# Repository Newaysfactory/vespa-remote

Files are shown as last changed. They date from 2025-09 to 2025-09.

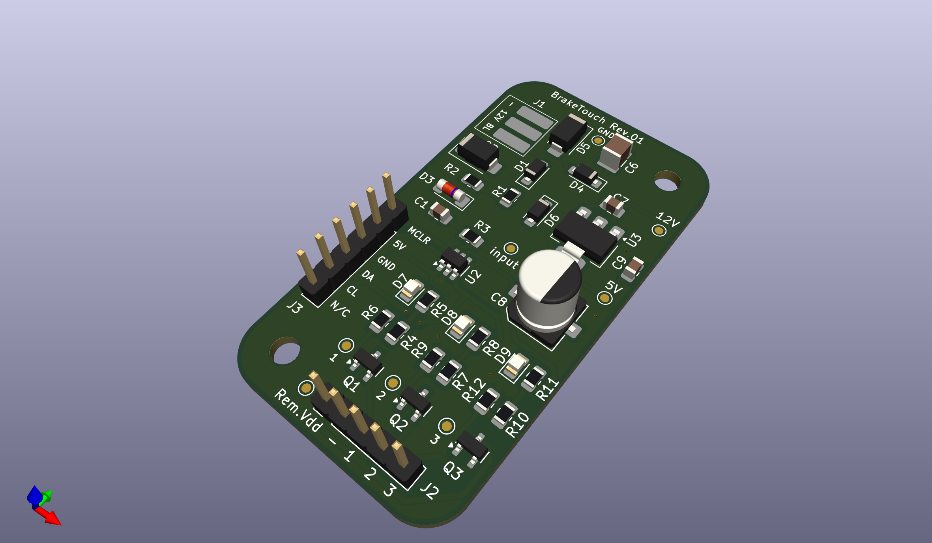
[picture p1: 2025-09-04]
electronics/KiCAD/Drawings/rev1/3DVespaRemoteControl-Front30deg.png

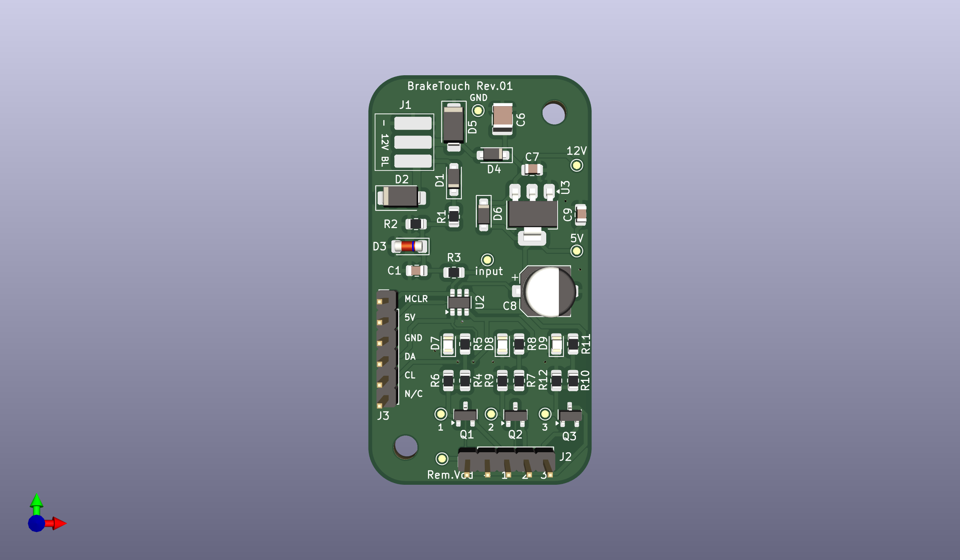
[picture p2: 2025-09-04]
electronics/KiCAD/Drawings/rev1/3DVespaRemoteControl-FrontSmall.png

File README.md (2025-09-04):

# vespa-remote
Vespa remote project - a microcontroller based circuit to trigger a gate remote using brake light signal on my Piaggio Vespa
See related youtube video https://youtu.be/zYhpTBYlj2o

## Repo content
 - Electronics - Contains the electronic hardware design (schematics and PCB) created with the free software KiCAD 8.0. Components part numbers are in the spreadsheet BOM_VespaRemoteControl.kicad_pcb.xls 
 - sw - Contains the sw project in MPLAB X IDE v6.25
 - mechanical - Contains the enclosure design in Rhinoceros 8 format. Standard STEP files are available under mechanical\fabrication\

Enjoy

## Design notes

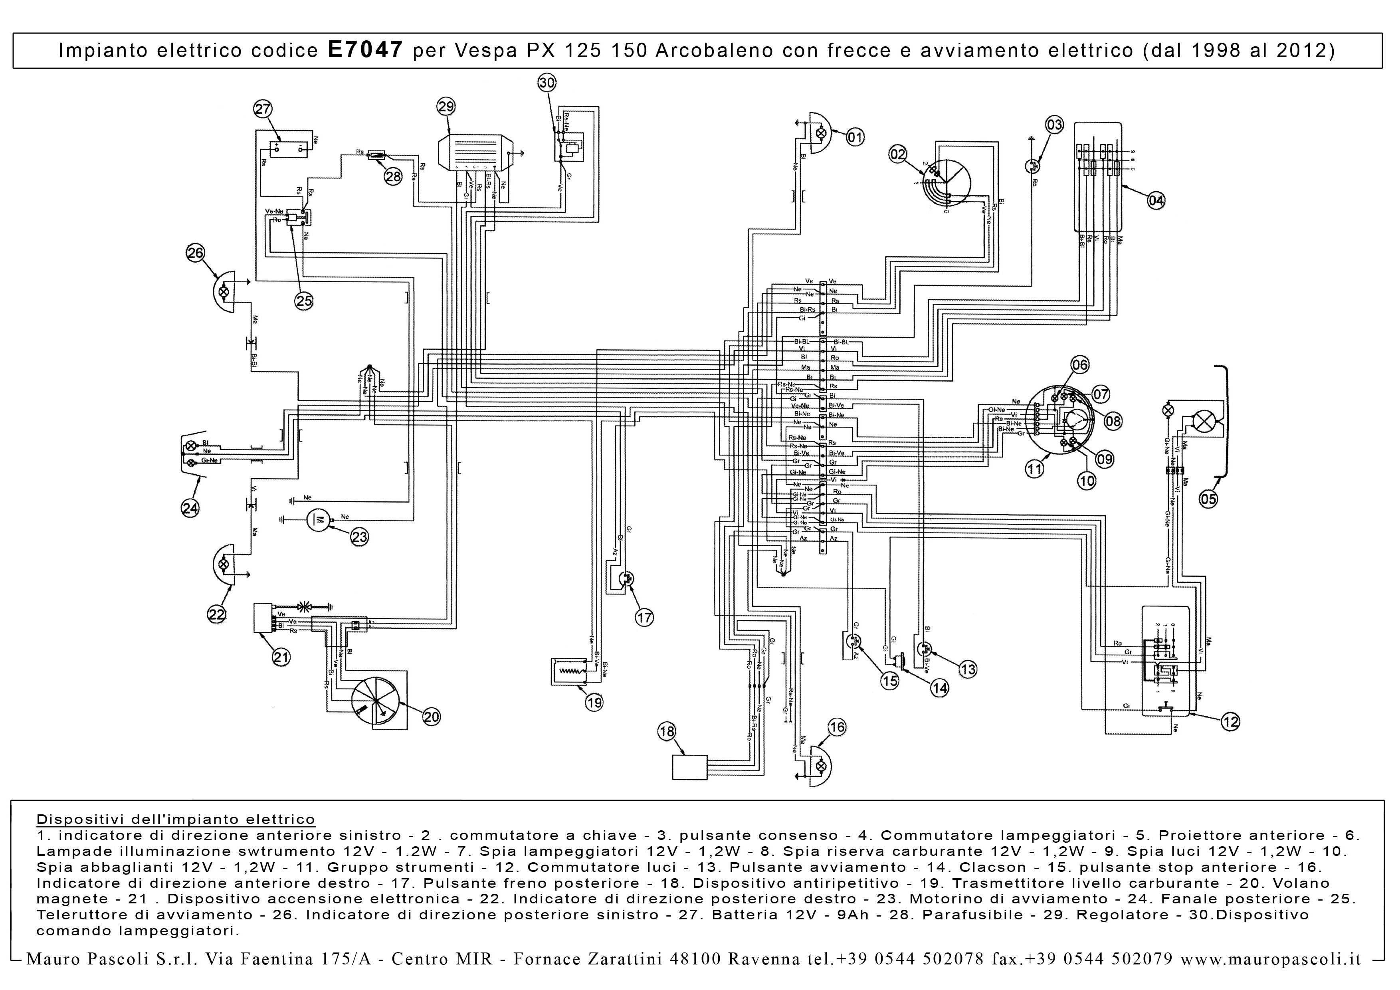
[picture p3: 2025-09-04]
VespaSchematicE7047.jpg

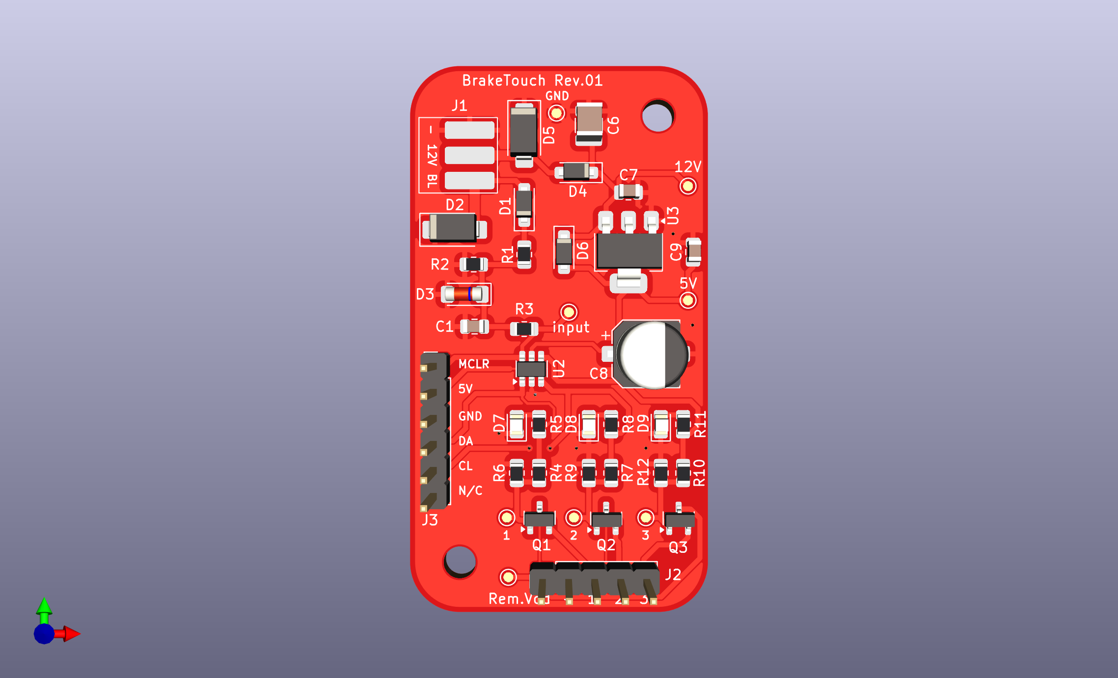
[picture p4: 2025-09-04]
electronics/KiCAD/Drawings/rev1/3DVespaRemoteControl-RedFrontSmall.png

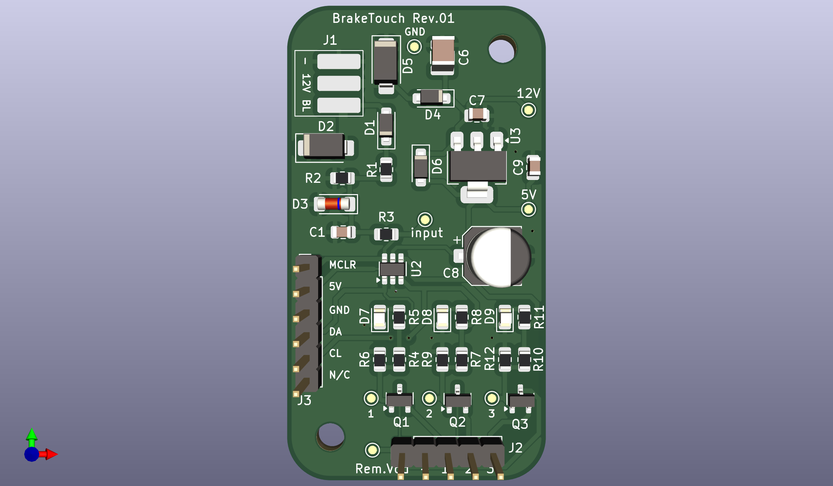
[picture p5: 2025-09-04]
electronics/KiCAD/Drawings/rev1/3DVespaRemoteControl-Front.png

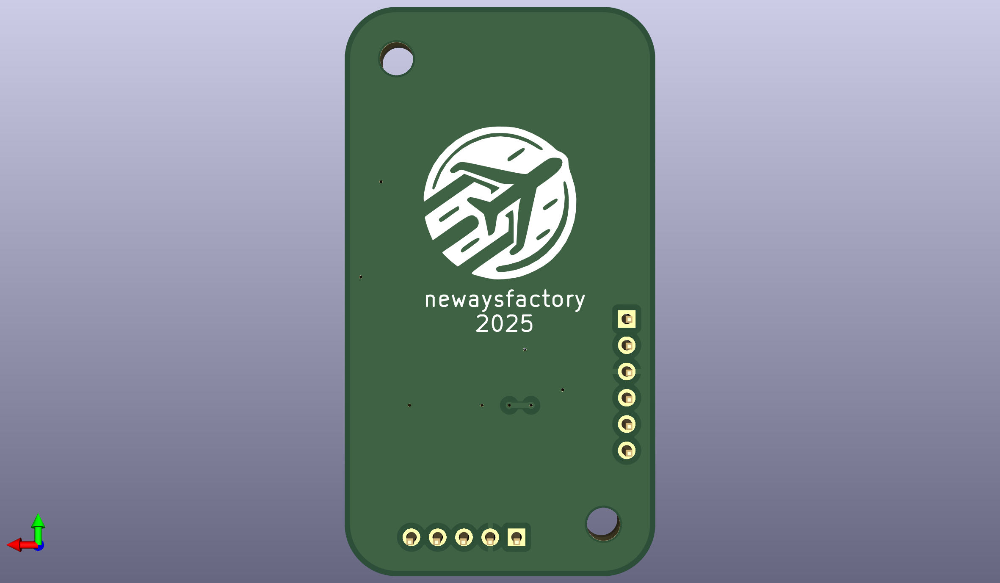
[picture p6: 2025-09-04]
electronics/KiCAD/Drawings/rev1/3DVespaRemoteControl-Back.png

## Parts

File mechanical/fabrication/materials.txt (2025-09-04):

Top cover:
Milled: Polycarbonate (PC) (transparent) Maximum service temperature	144 °C

Bottom:
3D printed: ABS

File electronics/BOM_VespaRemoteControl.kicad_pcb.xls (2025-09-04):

Designator | Quantity | Value | Footprint | Package | MPN | DNP | Mount_Type | Description | P/N
C1 | 1 | 330nF | C_0805_2012Metric |  |  |  | smt | Unpolarized capacitor, small symbol | CL21B334KBFNNNE
C6 | 1 | 10uF 100V | C_1210_3225Metric |  |  |  | smt | Unpolarized capacitor, small symbol | GRM32EC72A106KE05L
C7, C9 | 2 | 100nF100V | C_0805_2012Metric |  |  |  | smt | Unpolarized capacitor, small symbol | CL21B104KCFNNNE
C8 | 1 | 100uF | CP_Elec_6.3x7.7 |  |  |  | smt | Polarized capacitor, small symbol | EMZA350ARA101MF80G
D1, D4, D6 | 3 | 1n4007 | D_SOD-123FL |  |  |  | smt | Diode | 1N4007
D2, D5 | 2 | SMAJ30CA | D_SMA |  |  |  | smt | 400W bidirectional Transient Voltage Suppressor, 30.0Vr, SMA(DO-214AC) | SMAJ30CA
D3 | 1 | 4.7V | D_MiniMELF |  |  |  | smt | 4.7V, 500mW, 5%, Zener diode, MiniMELF | BZV55C4V7
D7, D8, D9 | 3 | LED red | LED_0805_2012Metric |  |  |  | smt | Light emitting diode | NCD0805R1
J2 | 1 | Conn_01x05 | PinHeader_1x05_P2.54mm_Vertical |  |  |  | tht | Generic connector, single row, 01x05, script generated (kicad-library-utils/schlib/autogen/connector/) | PinHeader_1x05_P2.54mm_Vertical
J3 | 1 | Conn_PIC_ICSP_ICD | PinHeader_1x06_P2.54mm_Vertical |  |  |  | tht | Microchip PIC In-Circuit Serial Programming/Debugging (ICSP/ICD) connector | PinHeader_1x06_P2.54mm_Vertical
Q1, Q2, Q3 | 3 | BC817 | SOT-23 |  |  |  | smt | 0.8A Ic, 45V Vce, NPN Transistor, SOT-23 | BC817
R1, R11, R5, R8 | 4 | 1,5k | R_0805_2012Metric |  |  |  | smt | Resistor | 0805W8F1501T5E
R10, R3, R4, R7 | 4 | 10k | R_0805_2012Metric |  |  |  | smt | Resistor | 0805W8F1002T5E
R12, R6, R9 | 3 | 100k | R_0805_2012Metric |  |  |  | smt | Resistor | 0805W8F1003T5E
R2 | 1 | 47k | R_0805_2012Metric |  |  |  | smt | Resistor | 0805W8F4702T5E
TP1, TP3, TP4, TP5, TP6, TP7, TP8, TP9 | 8 | TestPoint | My-TestPoint_Pad_D1.0mm |  |  |  | tht | test point
U2 | 1 | PIC10F222 | SOT-23-6 |  |  |  | smt | 512W Flash, 24B SRAM, SOT-23-6 | PIC10F222T-E/OT
U3 | 1 | TLV1117-50 | SOT-223-3_TabPin2 |  |  |  | smt | 800mA Low-Dropout Linear Regulator, 5.0V fixed output, TO-220/TO-252/TO-263/SOT-223 | TLV1117-50IDCY

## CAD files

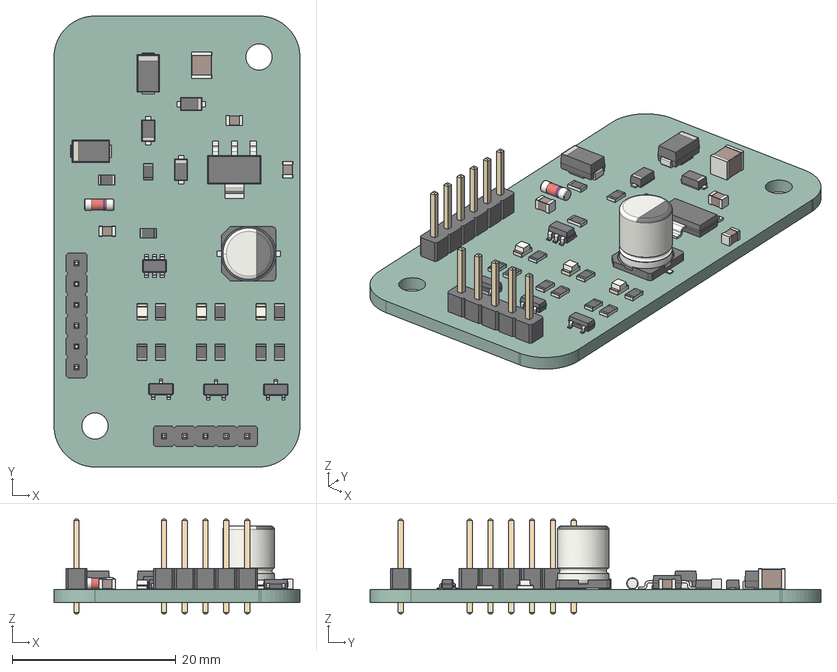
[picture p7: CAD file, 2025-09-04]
electronics/KiCAD/Drawings/rev1/VespaRemoteControl.step
30.0 x 55.0 x 11.5 mm
R_0805_2012Metric x 12
PinHeader_1x05_P254mm_Vertical
C_0805_2012Metric x 3
SOT_223
C_1210_3225Metric
CP_Elec_63x77
SOT_23 x 3
LED_0805_2012Metric x 3
D_SMA x 2
D_SOD_123F x 3
PinHeader_1x06_P254mm_Vertical
D_MiniMELF_Standard
SOT_23_6
_autosave-VespaRemoteControl_PCB

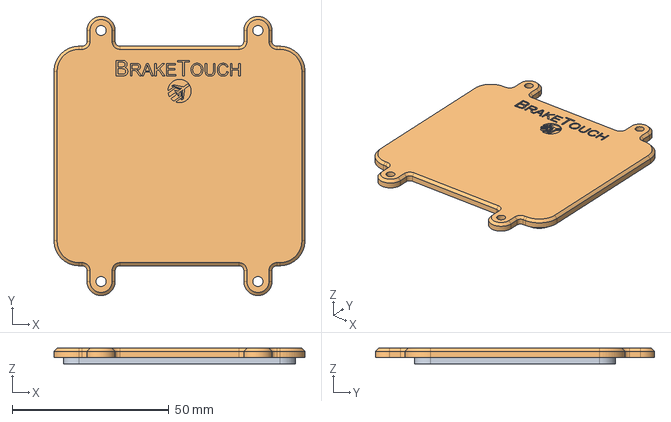
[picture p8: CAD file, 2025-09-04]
mechanical/fabrication/EnclosureTop_v2.stp
80.0 x 89.0 x 5.00 mm

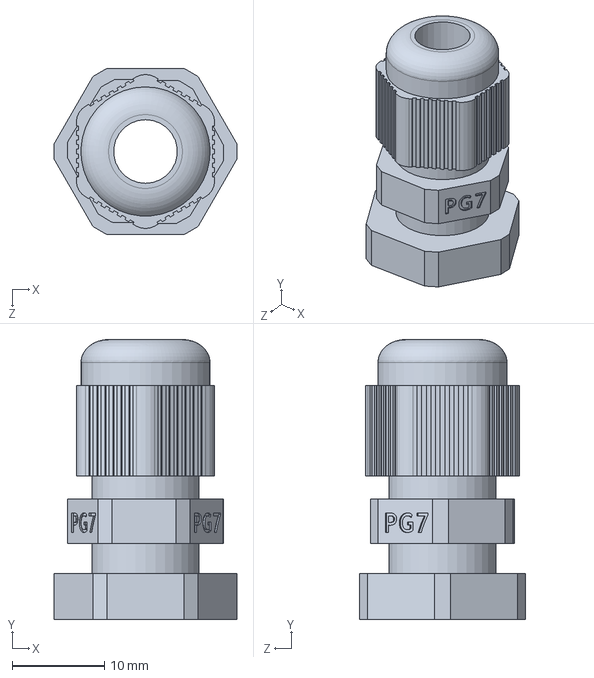
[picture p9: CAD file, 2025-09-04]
mechanical/PG7 cable gland.SLDPRT
19.8 x 30.4 x 18.0 mm

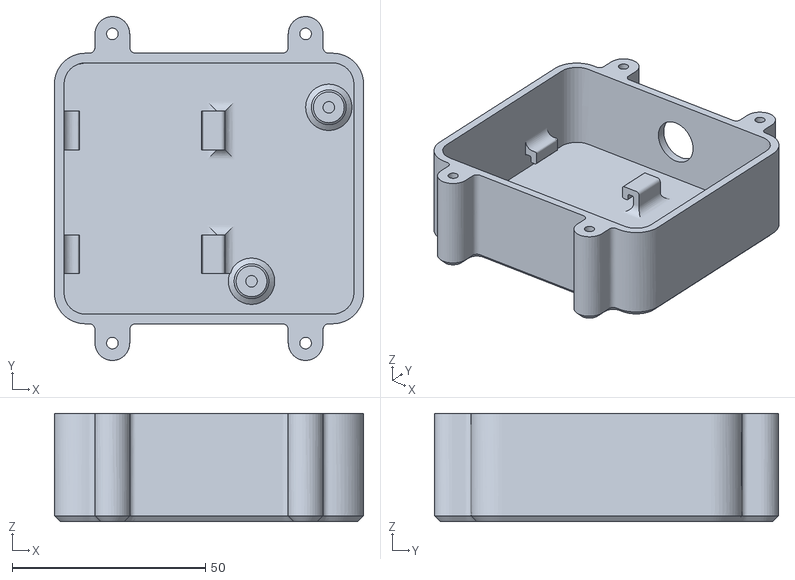
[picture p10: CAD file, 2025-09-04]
mechanical/fabrication/EnclosureBottom_v2.stl
80.0 x 89.0 x 28.0

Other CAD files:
mechanical/RemoteController.3dm

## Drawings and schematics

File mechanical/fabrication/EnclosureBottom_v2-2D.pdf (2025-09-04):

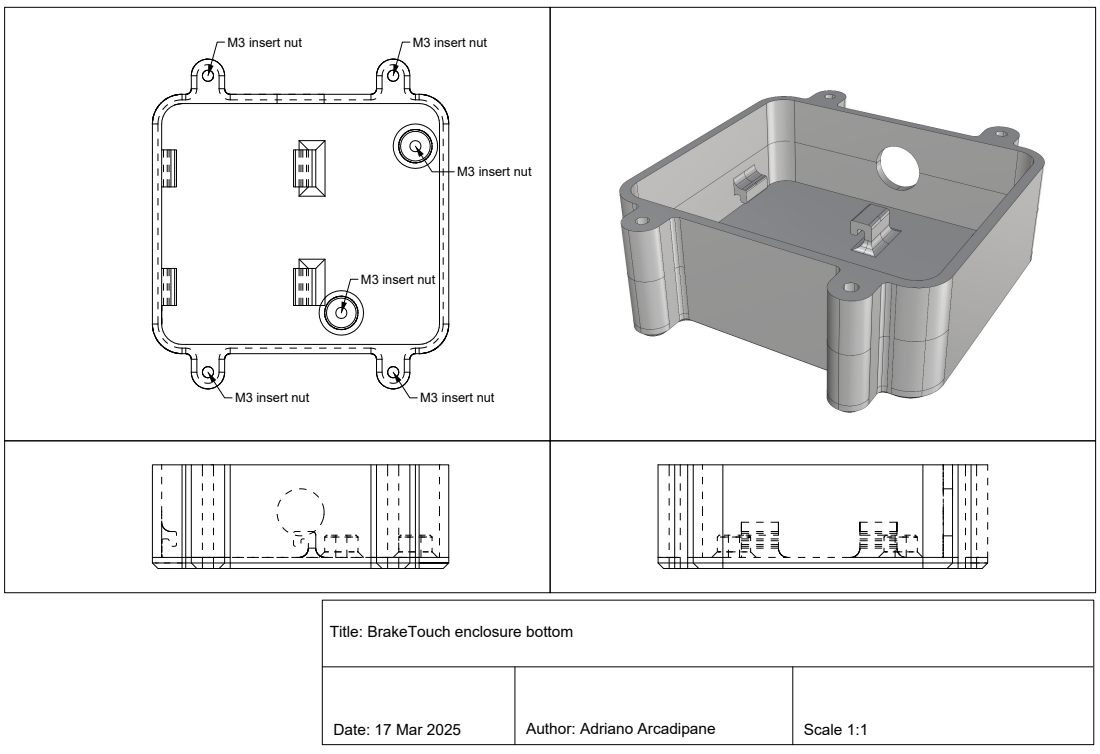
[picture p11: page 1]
M3 insert nut; Date: 17 Mar 2025; Author: Adriano Arcadipane; Scale 1:1

Title: BrakeTouch enclosure bottom

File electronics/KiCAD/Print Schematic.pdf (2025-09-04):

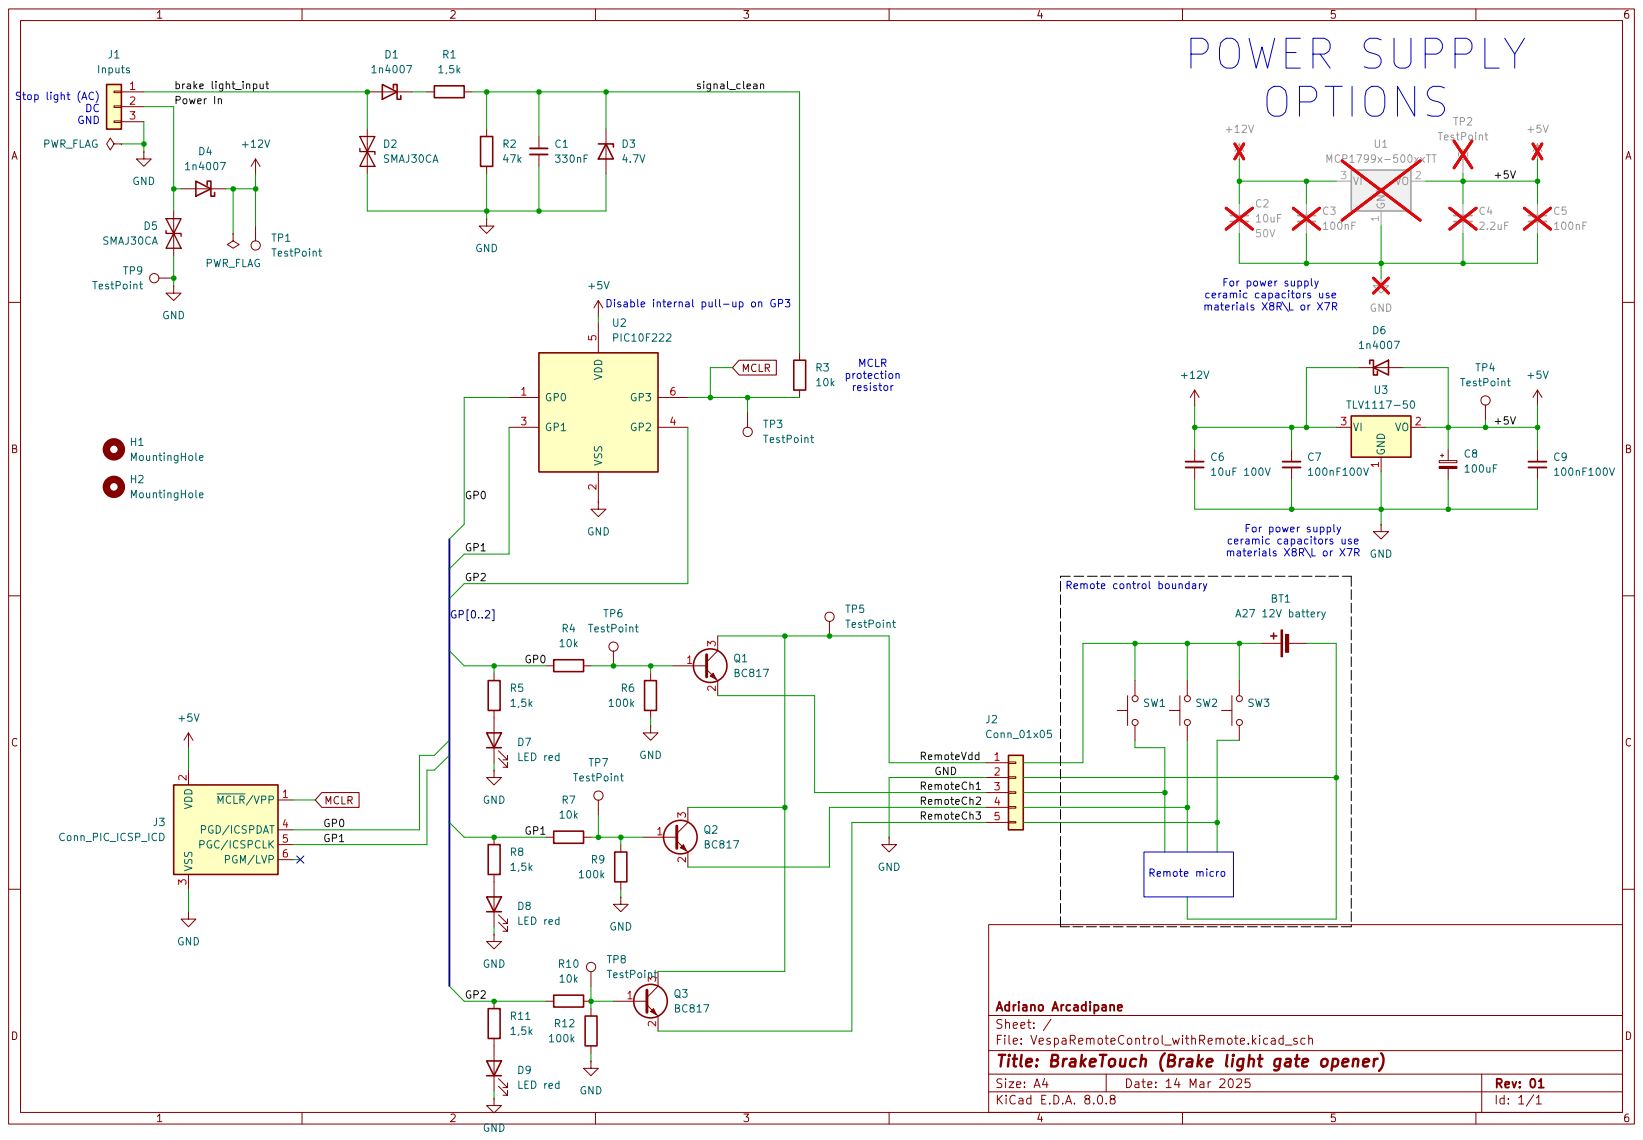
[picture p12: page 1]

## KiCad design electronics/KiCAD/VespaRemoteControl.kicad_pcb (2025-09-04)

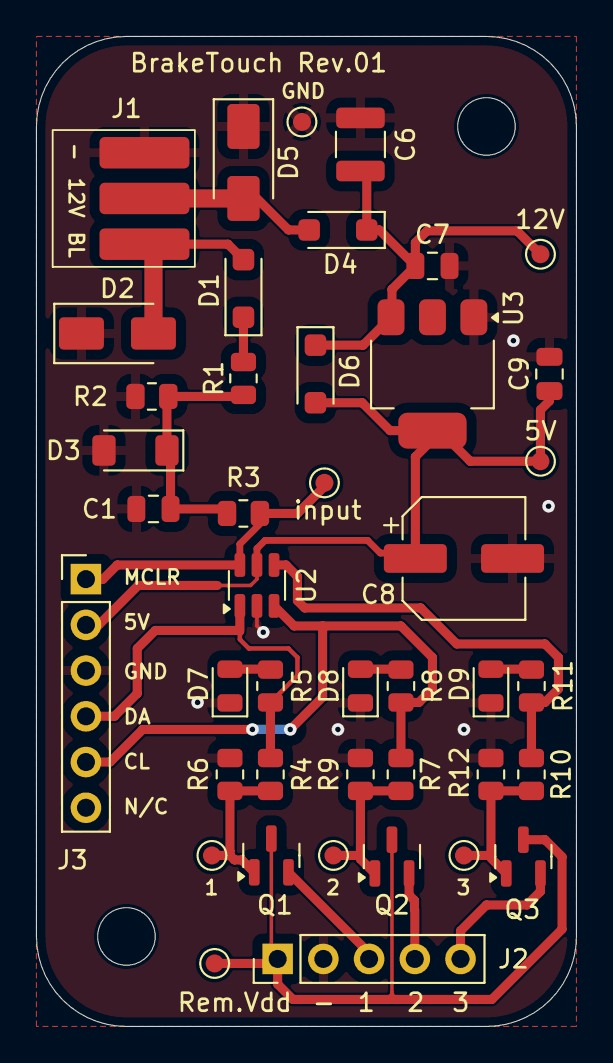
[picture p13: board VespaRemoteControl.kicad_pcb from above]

Board: 2 copper layers, 30.0 x 55.0 mm, 44 parts (0 on the bottom side), 21 nets.

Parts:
C1: 330nF; C_0805_2012Metric
C6: 10uF 100V; C_1210_3225Metric
C7, C9: 100nF100V; C_0805_2012Metric
C8: 100uF; CP_Elec_6.3x7.7
D1, D4, D6: 1n4007; D_SOD-123FL
D2, D5: SMAJ30CA; D_SMA
D3: 4.7V; D_MiniMELF
D7, D8, D9: LED red; LED_0805_2012Metric
H1, H2: MountingHole; MountingHole_3.2mm_M3
J1: Inputs; SolderWirePad_1x03_SMD_5x2mm
J2: Conn_01x05; PinHeader_1x05_P2.54mm_Vertical
J3: Conn_PIC_ICSP_ICD; PinHeader_1x06_P2.54mm_Vertical
Q1, Q2, Q3: BC817; SOT-23
R1, R5, R8, R11: 1,5k; R_0805_2012Metric
R2: 47k; R_0805_2012Metric
R3, R4, R7, R10: 10k; R_0805_2012Metric
R6, R9, R12: 100k; R_0805_2012Metric
TP1, TP3, TP4, TP5, TP6, TP7, TP8, TP9: TestPoint; My-TestPoint_Pad_D1.0mm
U2: PIC10F222; SOT-23-6
U3: TLV1117-50; SOT-223-3_TabPin2

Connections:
+5V: C8.1, C9.1, D6.2 (A), J3.2 (VDD), TP4.1, U2.5 (VDD), U3.2 (VO)
+12V: C6.1, C7.1, D4.1 (K), D6.1 (K), TP1.1, U3.3 (VI)
/GP0: J3.4 (PGD/ICSPDAT), R4.1, R5.1, U2.1 (GP0)
/GP1: J3.5 (PGC/ICSPCLK), R7.1, R8.1, U2.3 (GP1)
/GP2: R10.1, R11.1, U2.4 (GP2)
/Power In: D4.2 (A), D5.2 (A2), J1.2
/RemoteCh1: J2.3, Q1.2 (E)
/RemoteCh2: J2.4, Q2.2 (E)
/RemoteCh3: J2.5, Q3.2 (E)
/RemoteVdd: J2.1, Q1.3 (C), Q2.3 (C), Q3.3 (C), TP5.1
/brake light_input: D1.2 (A), D2.2 (A2), J1.1
/signal_clean: C1.1, D3.1 (K), R1.1, R2.1, R3.2
GND: C1.2, C6.2, C7.2, C8.2, C9.2, D2.1 (A1), D3.2 (A), D5.1 (A1), D7.1 (K), D8.1 (K), D9.1 (K), J1.3, J2.2, J3.3 (VSS), R2.2, R6.1, R9.1, R12.1, TP9.1, U2.2 (VSS), U3.1 (GND)
MCLR: J3.1 (~MCLR/VPP), R3.1, TP3.1, U2.6 (GP3)
unnamed: D1.1 (K), R1.2
unnamed: D7.2 (A), R5.2
unnamed: D8.2 (A), R8.2
unnamed: D9.2 (A), R11.2
unnamed: Q1.1 (B), R4.2, R6.2, TP6.1
unnamed: Q2.1 (B), R7.2, R9.2, TP7.1
unnamed: Q3.1 (B), R10.2, R12.2, TP8.1

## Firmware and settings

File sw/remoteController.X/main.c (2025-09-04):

/*
 * File:   main.c
 * Author: Adriano Arcadipane
 *
 * Created on December 25, 2024, 6:51 PM
 */

#include <xc.h>

// PIC10F222 Configuration Bit Settings

// CONFIG
#pragma config IOSCFS = 4MHZ    // Internal Oscillator Frequency Select bit (4 MHz)
#pragma config MCPU = OFF       // Master Clear Pull-up Enable bit (Pull-up disabled)
#pragma config WDTE = OFF       // Watchdog Timer Enable bit (WDT disabled)
#pragma config CP = OFF         // Code protection bit (Code protection off)
#pragma config MCLRE = OFF      // GP3/MCLR Pin Function Select bit (GP3/MCLR pin function is digital I/O, MCLR internally tied to VDD)

#define _XTAL_FREQ 4000000      // Internal frequency 4 MHz (for delay function)

#define OBSERVATION_TIME_MS 1000 // After first brake pressure, the software counts the pressures within thi time
#define CYCLE_TIME_MS 2         // Cycle time
#define REMOTE_TIME_ON_MS_1 1000   // Time the remote control is kept in transmission
#define REMOTE_TIME_ON_MS_2 500   // Time the remote control is kept in transmission

#define TRUE  1
#define FALSE 0

// I/O definitions
#define BRAKE_LIGHT GP3       // Brake light input
#define OUT1 GP0              // Output 1
#define OUT2 GP1              // Output 2
#define OUT3 GP2              // Output 3

void init(){
    //REQUIREMENTS TO MAKE PINS AVAILABLE IN DIGITAL MODE
    ADCON0bits.ANS0 = 0;  //Disable analog input 
    ADCON0bits.ANS1 = 0;  //Disable analog input 
    OSCCALbits.FOSC4 = 0; //Disable TMR input from GP2
    
    //0 GPWU: Enable Wake-up On Pin Change bit (GP0, GP1, GP3)
    //1 GPPU: Disable Weak Pull-ups bit (GP0, GP1, GP3)
    //0 T0CS: Timer0 Clock Source Select bit - Transition on internal instruction cycle clock, FOSC/4
    OPTION = 0b01011111;

    // Set GP0, GP1, GP2 as digital output, GP3 as input
    TRISGPIO = 0b11111000;    // (0 = output, 1 = input)
    GPIO = 0b00000000;        // Init outputs low (0)
}

unsigned char debouncePin(unsigned char raw_state){
    // Change the state when the raw state has the same value 8 consecutive
    // samples
    static unsigned char debounced_state = FALSE;
    static unsigned char candidate_state = 0;

    // candidate_state contains the last 8 raw readings.
    // Each time the function is called, candidate_state content is shifted 
    // left of one bit and the new raw value is added as LSB
    candidate_state = (unsigned char)((candidate_state << 1) | raw_state);
    
    if  (candidate_state == 0xff){ //When input is TRUE for 8 times
        debounced_state = TRUE;
    }
    else  if (candidate_state == 0x00){ //When input is FALSE for 8 times
        debounced_state = FALSE;
    }
    return  debounced_state;
}


void main(void) {
    unsigned char rising_edges_cnt = 0;
    unsigned int cycle = 0;
    unsigned char prev_state = FALSE;
    unsigned char state = FALSE;
    
    init();
    
    while(1){
        //Read the raw input and debounce it
        state = debouncePin(BRAKE_LIGHT);
        
        //Detect rising edge of the input
        if (prev_state == 0 && state == 1) {
            if (rising_edges_cnt < 255) {  //Guard against overflow
                rising_edges_cnt++;
            }
                cycle = 0; //Restart the timer every time the brake lever is pressed
        }
        
        //The timer ticks only when the brake has been pressed at least once
        if (rising_edges_cnt){
            cycle++;
        }
        
        //When the timer expires, activate the output
        if (cycle >= OBSERVATION_TIME_MS/CYCLE_TIME_MS){
            if (rising_edges_cnt == 1){
            ; //Do nothing. We don't want to trigger the output when braking just once
            } else if (rising_edges_cnt == 2){
                OUT1 = 1;
                __delay_ms(REMOTE_TIME_ON_MS_1); //Keep output high for some time
            } else if (rising_edges_cnt == 3){
                OUT2 = 1;
                __delay_ms(REMOTE_TIME_ON_MS_1); //Keep outputs high for some time
            } else if (rising_edges_cnt == 4){
                OUT3 = 1;
                __delay_ms(REMOTE_TIME_ON_MS_2); //Keep outputs high for some time
            }else {
                ; //Do nothing
            }
            
            cycle = 0; //Reset timer
            rising_edges_cnt = 0; //Reset input counts
        }
        
        //Update the previous state for the next cycle
        prev_state = state;
        //Set all outputs low
        OUT1 = 0;
        OUT2 = 0;
        OUT3 = 0;
        //Sleep
        __delay_ms(CYCLE_TIME_MS);
    }// end while(1)

}//end main

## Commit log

2025-09-04 Adding all files
    [EnclosureBottom_v2.stl, EnclosureTop_v2.stp, PG7 cable gland.SLDPRT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]
2025-09-04 Fixing material error
2025-09-04 Adding bill of materials
    [BOM_VespaRemoteControl.kicad_pcb.xls]
